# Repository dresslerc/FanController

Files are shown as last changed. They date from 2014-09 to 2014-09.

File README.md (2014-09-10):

FanController - Ceiling Fan Controller 
=========================================

Summary:
This project contains everything you need in order to control your Ceiling Fans from your smart phone.  We do this by tapping into the orginal RF remote of your fan by using Optocouplers. 

There are 3 key components to this project (1 Custom PCB Board, 2 Spark Core Code, and 3 Android/Android Wear app)

The PCB Board can be manufactured at OSHPark (https://oshpark.com/) for about 15$ with a 1-2 week turn around.  In the 'Docs' folder you will find a BOM that contains everything you need to build the board.

The controller for the circuit board is a Spark Core (http://spark.io).  The code is in 'Spark' folder.

You can find the oringal post for this project on https://community.spark.io/t/ceiling-fan-controller/6170

A video of the Android App: https://www.youtube.com/watch?v=2CFPBg5slgM

Android Weaer App: https://www.youtube.com/watch?v=zdxXlhGC8Go

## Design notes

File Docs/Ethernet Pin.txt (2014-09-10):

Color T-568A	Color T-568B	Pin	Description
Brown			Brown			8	GND
Brown/White		Brown/White		7	Fan High
Orange			Green			6	Fan Mid
Blue/White		Blue/White		5	Fan Low
Blue			Blue			4	Fan Off
Orange/White		Green/White		3	DIP 3
Green			Orange			2	DIP 2
Green/White		Orange/White		1	DIP 1

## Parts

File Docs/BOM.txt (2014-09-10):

BOM

Item			Quantity	Unit Price	Total Price		Link	
Female Headers		1		$1.50		$1.50			https://www.sparkfun.com/products/115	
Optoisolator		7		$0.95		$6.65			https://www.sparkfun.com/products/314	
LED 3mm			7		$0.35		$2.45			https://www.sparkfun.com/products/9650	
RJ45 8-Pin		1		$1.50		$1.50			https://www.sparkfun.com/products/643	
Custom PCB		1		$7.73		$7.73		
Spark Core		1		$39.00		$39.00			https://www.spark.io/#

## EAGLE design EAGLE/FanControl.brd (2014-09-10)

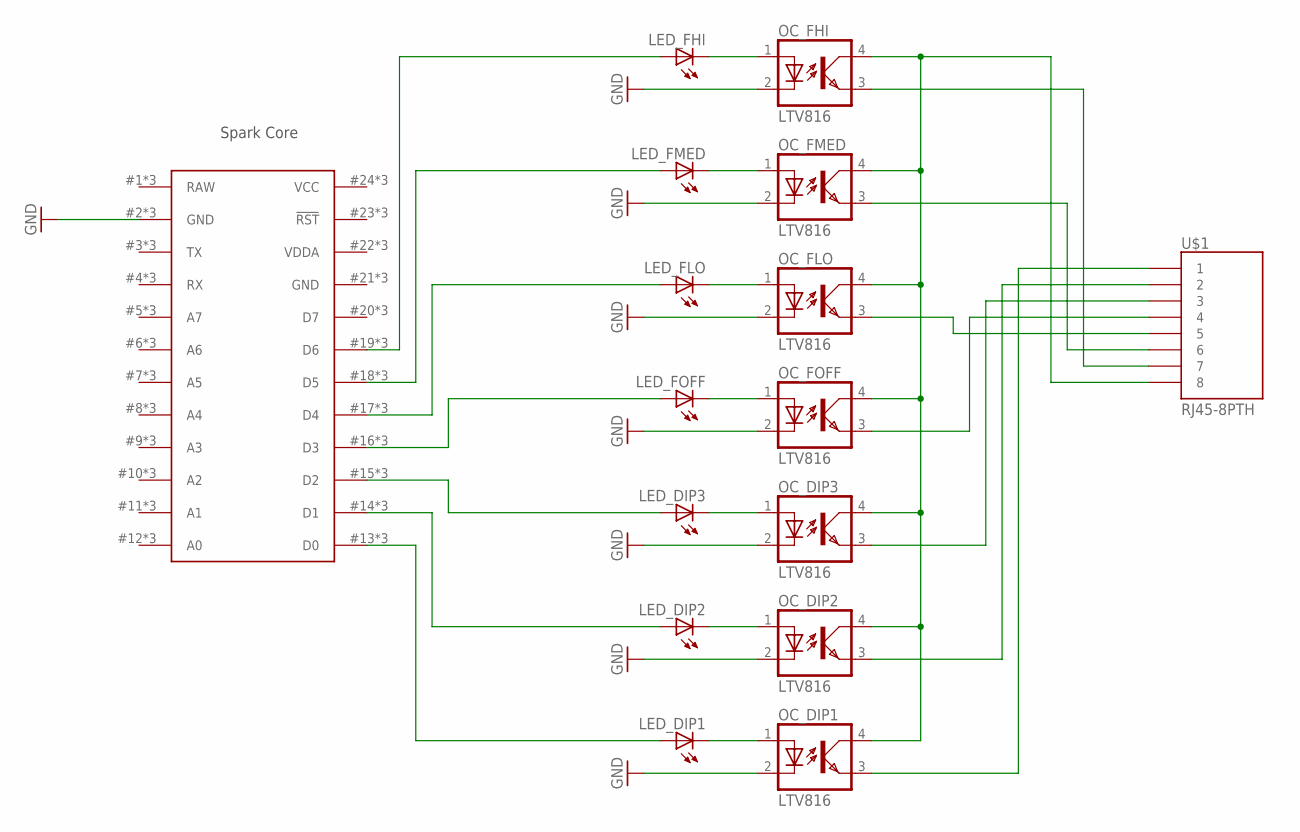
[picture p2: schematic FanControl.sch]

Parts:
LED_DIP1, LED_DIP2, LED_DIP3: LED3MM
LED_FHI: LED3MM
LED_FLO: LED3MM
LED_FMED: LED3MM
LED_FOFF: LED3MM
OC_DIP1, OC_DIP2, OC_DIP3: LTV816; DIL04
OC_FHI: LTV816; DIL04
OC_FLO: LTV816; DIL04
OC_FMED: LTV816; DIL04
OC_FOFF: LTV816; DIL04
U$1: RJ45-8PTH; RJ45-8
U$2: SPARK_CORE; SPARK_CORE_STACKABLE

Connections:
GND: OC_DIP1.2 (C), OC_DIP2.2 (C), OC_DIP3.2 (C), OC_FHI.2 (C), OC_FLO.2 (C), OC_FMED.2 (C), OC_FOFF.2 (C), U$2.2 (GND), U$2.21 (GND), U$2.#2 (GND), U$2.#21 (GND), U$2.@2 (GND), U$2.@21 (GND)
unnamed: OC_DIP1.4 (COL), OC_DIP2.4 (COL), OC_DIP3.4 (COL), OC_FHI.4 (COL), OC_FLO.4 (COL), OC_FMED.4 (COL), OC_FOFF.4 (COL), U$1.8
unnamed: OC_DIP1.3 (EMIT), U$1.1
unnamed: OC_DIP2.3 (EMIT), U$1.2
unnamed: OC_DIP3.3 (EMIT), U$1.3
unnamed: OC_FOFF.3 (EMIT), U$1.4
unnamed: OC_FLO.3 (EMIT), U$1.5
unnamed: OC_FMED.3 (EMIT), U$1.6
unnamed: OC_FHI.3 (EMIT), U$1.7
unnamed: LED_FHI.K (C), OC_FHI.1 (A)
unnamed: LED_FMED.K (C), OC_FMED.1 (A)
unnamed: LED_FLO.K (C), OC_FLO.1 (A)
unnamed: LED_FOFF.K (C), OC_FOFF.1 (A)
unnamed: LED_DIP3.K (C), OC_DIP3.1 (A)
unnamed: LED_DIP2.K (C), OC_DIP2.1 (A)
unnamed: LED_DIP1.K (C), OC_DIP1.1 (A)
unnamed: LED_DIP1.A, U$2.13 (D0), U$2.#13 (D0), U$2.@13 (D0)
unnamed: LED_DIP2.A, U$2.14 (D1), U$2.#14 (D1), U$2.@14 (D1)
unnamed: LED_DIP3.A, U$2.15 (D2), U$2.#15 (D2), U$2.@15 (D2)
unnamed: LED_FOFF.A, U$2.16 (D3), U$2.#16 (D3), U$2.@16 (D3)
unnamed: LED_FLO.A, U$2.17 (D4), U$2.#17 (D4), U$2.@17 (D4)
unnamed: LED_FMED.A, U$2.18 (D5), U$2.#18 (D5), U$2.@18 (D5)
unnamed: LED_FHI.A, U$2.19 (D6), U$2.#19 (D6), U$2.@19 (D6)
RAW: U$2.1 (RAW), U$2.#1 (RAW), U$2.@1 (RAW)
VCC: U$2.24 (VCC), U$2.#24 (VCC), U$2.@24 (VCC)
VDDA: U$2.22 (VDDA), U$2.#22 (VDDA), U$2.@22 (VDDA)

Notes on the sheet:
Spark Core

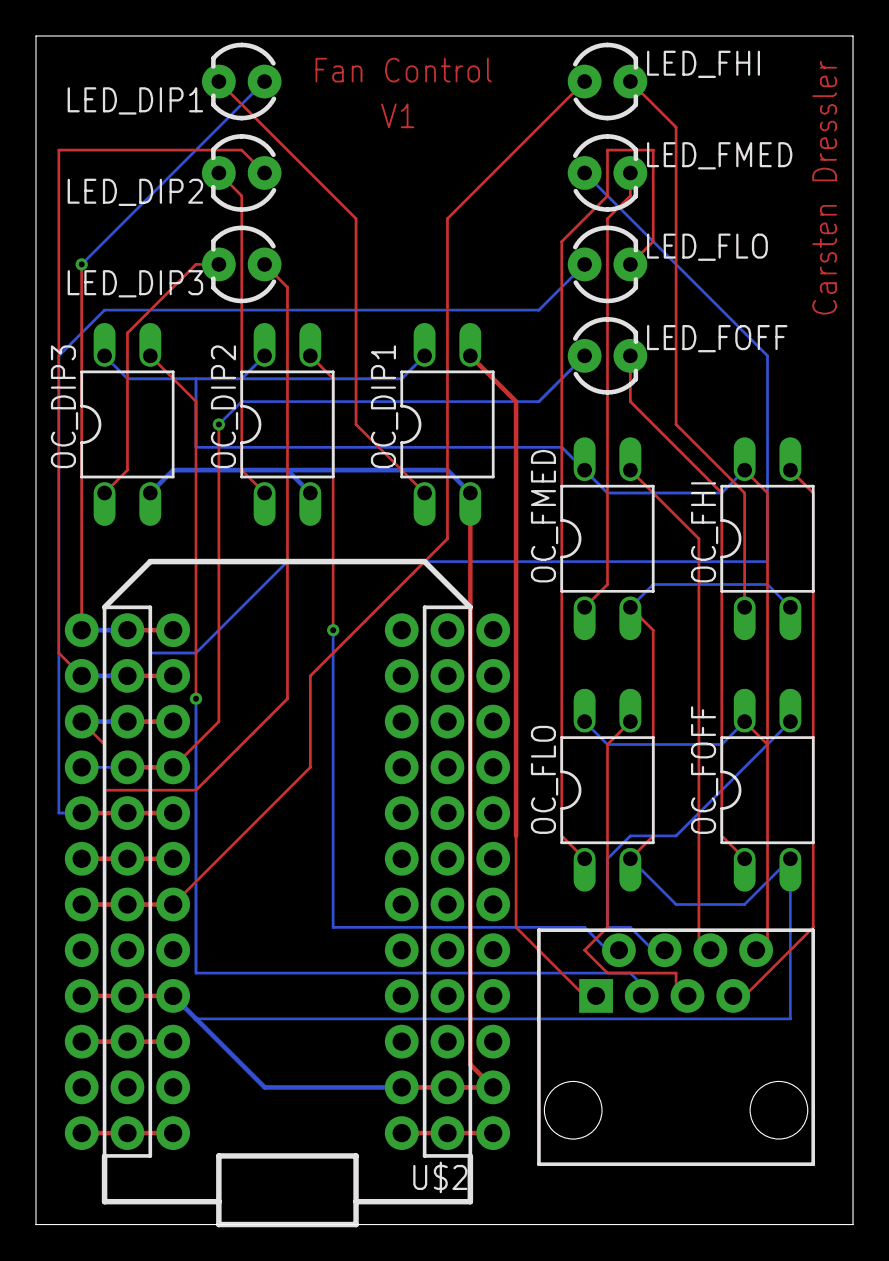
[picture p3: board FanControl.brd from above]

Board: 2 copper layers, 45.4 x 66.0 mm, 16 parts (0 on the bottom side), 26 nets.

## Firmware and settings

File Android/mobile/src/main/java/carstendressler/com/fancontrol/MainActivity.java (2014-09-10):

package carstendressler.com.fancontrol;

import android.app.Activity;
import android.app.AlertDialog;
import android.app.ListActivity;
import android.content.Context;
import android.content.DialogInterface;
import android.content.Intent;
import android.os.Bundle;
import android.util.Log;
import android.view.Menu;
import android.view.MenuItem;
import android.view.View;
import android.view.Window;
import android.widget.ListView;
import android.widget.Toast;

import com.google.gson.Gson;
import com.google.gson.internal.LinkedTreeMap;

import java.io.IOException;
import java.util.ArrayList;
import java.util.HashMap;
import java.util.List;
import java.util.Map;

import carstendressler.com.util.HTTPHeader;
import carstendressler.com.util.SimpleHttpClient;
import carstendressler.com.util.SparkResponse;
import io.spark.core.cloud.AuthenicationResponse;

/**
 * Created by Carsten on 7/25/2014.
 */
public class MainActivity extends ListActivity {

    private FanAdapter _adapter;
    private List<FanEntity> _fans = null; //new ArrayList<FanEntity>();
    private Context _context;
    private Activity _activity;

    //public String _accessToken = "9f144d072f915ab729d60e724282d36ce44bc310";
    //public String _deviceId = "48ff70065067555030231387";

    @Override
    protected void onCreate(Bundle savedInstanceState) {
        super.onCreate(savedInstanceState);
        // setContentView(R.layout.activity_main);
        Log.v("FANCTRL", "appcreated");
        this.requestWindowFeature(Window.FEATURE_INDETERMINATE_PROGRESS);

        _context = this;
        _activity = this;

        _fans =  SettingsActivity.SettingsFragment.getConfiguredFans(_context);

        _adapter = new FanAdapter(this, R.layout.listitem, _fans);
        this.setListAdapter(_adapter);

        _adapter.notifyDataSetChanged();

        getStatus();

    }

    @Override
    protected void onResume() {
        super.onResume();

        _fans.clear();
        _fans.addAll(SettingsActivity.SettingsFragment.getConfiguredFans(_context));

        _adapter.notifyDataSetChanged();

        getStatus();
    }

    @Override
    protected void onListItemClick(ListView l, View v, final int position,
                                   long id) {
        // TODO Auto-generated method stub
        super.onListItemClick(l, v, position, id);

        AlertDialog.Builder builder = new AlertDialog.Builder(_context);
        builder.setTitle("Set Fan Mode");
        builder.setItems(R.array.mode_array,
                new DialogInterface.OnClickListener() {
                    public void onClick(DialogInterface dialog, int which) {
                        // _fans.get(position).Name
                        String mode = null;

                        if (which == 0)
                            mode = "hi";

                        if (which == 1)
                            mode = "me";

                        if (which == 2)
                            mode = "lo";

                        if (which == 3)
                            mode = "of";

                        SendCommand(
                                String.valueOf(_fans.get(position).Address),
                                mode);

                        // Toast.makeText(_context,
                        // String.valueOf(_fans.get(position).Address),
                        // Toast.LENGTH_LONG).show();

                    }
                });
        builder.show();

    }

    @Override
    public boolean onCreateOptionsMenu(Menu menu) {
        // Inflate the menu; this adds items to the action bar if it is present.
        getMenuInflater().inflate(R.menu.main, menu);
        return true;
    }


    @Override
    public boolean onMenuItemSelected(int featureId, MenuItem item) {

        switch (item.getItemId()) {
            case R.id.action_settings:

                Intent SettingsIntent = new Intent(_context, SettingsActivity.class);
                this.startActivity(SettingsIntent);
                break;

            case R.id.action_refresh:

                getStatus();

                break;

        }

        return super.onMenuItemSelected(featureId, item);
    }



    private void SendCommand(final String Address, final String Mode) {

        final String deviceID = SettingsActivity.SettingsFragment.getDeviceID(_context);

        Toast.makeText(_context, Address + Mode, Toast.LENGTH_LONG).show();

        new Thread(new Runnable() {
            public void run() {

                Gson gson = new Gson();
                String buffer = null;

                try {
                    buffer = SimpleHttpClient.httpPost("https://api.spark.io/v1/devices/" + deviceID + "/fancontrol","access_token=" + SettingsActivity.SettingsFragment.getAccessToken(_context) + "&args=" + Address + Mode);

                    SparkResponse resp = gson.fromJson(buffer, SparkResponse.class);

                    int ArrayAddress = 0;
                    for (int i = 0; i < _fans.size(); i++) {
                        if (_fans.get(i).Address == Integer.valueOf(Address))
                            ArrayAddress = i;
                    }

                    if (resp.return_value == -1)
                        _fans.get(ArrayAddress).Status = FanEntity.Status1.UNKNOWN;

                    if (resp.return_value == 0)
                        _fans.get(ArrayAddress).Status = FanEntity.Status1.OFF;

                    if (resp.return_value == 1)
                        _fans.get(ArrayAddress).Status = FanEntity.Status1.LOW;

                    if (resp.return_value == 2)
                        _fans.get(ArrayAddress).Status = FanEntity.Status1.MEDIUM;

                    if (resp.return_value == 3)
                        _fans.get(ArrayAddress).Status = FanEntity.Status1.HIGH;

                    // Runs next code in UI Thread
                    _activity.runOnUiThread(new Runnable() {
                        public void run() {
                            _adapter.notifyDataSetChanged();

                        }
                    });

                } catch (IOException e) {
                    // TODO Auto-generated catch block
                    e.printStackTrace();
                }

            }
        }).start();

    }

    private void getStatus() {

        final String deviceID = SettingsActivity.SettingsFragment.getDeviceID(_context);

        if (deviceID.length() == 0)
            return;

        setProgressBarIndeterminateVisibility(Boolean.TRUE);

        new Thread(new Runnable() {
            public void run() {

                Gson gson = new Gson();
                String buffer = null;

                for (int i = 0; i < _fans.size(); i++) {

                    buffer = null;

                    try {
                        String accessToken = SettingsActivity.SettingsFragment.getAccessToken(_context);

                        if (accessToken.length() == 0) {
                            // Runs next code in UI Thread
                            _activity.runOnUiThread(new Runnable() {
                                public void run() {
                                    setProgressBarIndeterminateVisibility(Boolean.FALSE);
                                }
                            });

                            return;

                        }


                        buffer = SimpleHttpClient.httpPost("https://api.spark.io/v1/devices/" + deviceID + "/fanstatus" ,"access_token=" + accessToken + "&args=" + String.valueOf(_fans.get(i).Address));
                        SparkResponse resp = gson.fromJson(buffer, SparkResponse.class);

                        if (resp.return_value == -1)
                            _fans.get(i).Status = FanEntity.Status1.UNKNOWN;

                        if (resp.return_value == 0)
                            _fans.get(i).Status = FanEntity.Status1.OFF;

                        if (resp.return_value == 1)
                            _fans.get(i).Status = FanEntity.Status1.LOW;

                        if (resp.return_value == 2)
                            _fans.get(i).Status = FanEntity.Status1.MEDIUM;

                        if (resp.return_value == 3)
                            _fans.get(i).Status = FanEntity.Status1.HIGH;

                        // Runs next code in UI Thread
                        _activity.runOnUiThread(new Runnable() {
                            public void run() {
                                _adapter.notifyDataSetChanged();
                                setProgressBarIndeterminateVisibility(Boolean.FALSE);
                            }
                        });

                    } catch (final IOException e) {
                        // TODO Auto-generated catch block
                        e.printStackTrace();

                        final String errorMsg = buffer;

                        // Runs next code in UI Thread
                        _activity.runOnUiThread(new Runnable() {
                            public void run() {
                                _adapter.notifyDataSetChanged();
                                setProgressBarIndeterminateVisibility(Boolean.FALSE);
                                Toast.makeText(_context, e.getMessage(), Toast.LENGTH_LONG).show();

                            }
                        });


                    }
                }
            }
        }).start();
    }

    private void getAccessToken(final String Email, final String Password) {

        setProgressBarIndeterminateVisibility(Boolean.TRUE);

        new Thread(new Runnable() {
            public void run() {

                Map<String, String> jsonMap = new HashMap<String, String>();

                jsonMap.put("username",Email);
                jsonMap.put("password", Password);

                String json = new Gson().toJson(jsonMap);

                List<HTTPHeader> headers = new ArrayList<HTTPHeader>();
                headers.add(new HTTPHeader("Content-Type","application/json"));

                String respBuffer = null;
                try {
                    respBuffer = SimpleHttpClient.httpPost("https://www.spark.io/sign-in", json, headers);
                } catch (IOException e) {
                }
                AuthenicationResponse authResp = new Gson().fromJson(respBuffer, AuthenicationResponse.class);

                headers.add(new HTTPHeader("Authorization","Bearer " + authResp.auth_token.token));
                try {
                    respBuffer = SimpleHttpClient.httpGet("https://www.spark.io/access-token", headers);
                } catch (IOException e) {
                }
                LinkedTreeMap accessTokenResp = new Gson().fromJson(respBuffer, LinkedTreeMap.class);


            }
        }).start();

    }

}

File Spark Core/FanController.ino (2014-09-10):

const int io_dip1 = 0;
const int io_dip2 = 1;
const int io_dip3 = 2;
const int io_fanoff = 3;
const int io_fanlo = 4;
const int io_fanmed = 5;
const int io_fanhigh = 6;

int fanStat[7];

void setup() {
    
    for (int i = 0; i < 7; i++)  {
        fanStat[i] = -1;
    }
        
    // Controls onboard RGB led
    RGB.control(true);
    RGB.color(0, 0, 30);
    
    // Sets up Pins Modes
    pinMode(io_dip1, OUTPUT);
    pinMode(io_dip2, OUTPUT);
    pinMode(io_dip3, OUTPUT);
    pinMode(io_fanoff, OUTPUT);
    pinMode(io_fanlo, OUTPUT);
    pinMode(io_fanmed, OUTPUT);
    pinMode(io_fanhigh, OUTPUT);
  
    // Sets Cloud function calls
    Spark.function("fancontrol", fanControl);
    Spark.function("fanstatus", fanStatus);
    
    //Serial.begin(9600);
    
}

void loop() {

}

int fanStatus(String command)
{
    int address = command.toInt();;
    
    // Memory
    return fanStat[address];
    
    // EEPROM
    //return SparkFlash_read(address);
}

int fanControl(String command) 
{
   RGB.color(0, 30, 0);
   int address = setDipSwitches(command.substring(0,1));
   delay(200);
   
   // Memory
   fanStat[address] = setFanMode(command.substring(1));
   
   // EEPROM
   //SparkFlash_write(address * 2,  setFanMode(command.substring(1)));
   
   delay(1000);
   gpioReset();
   RGB.color(0, 0, 30);
   
   // Memory
   return fanStat[address];
   
   // EEPROM
   //return SparkFlash_read(address);
}

int setDipSwitches(String address) {
    
    if (address == "0") {
        digitalWrite(io_dip1, LOW);
        digitalWrite(io_dip2, LOW);
        digitalWrite(io_dip3, LOW);
        
        return 0;
    }
    
    if (address == "1") {
        digitalWrite(io_dip1, LOW);
        digitalWrite(io_dip2, LOW);
        digitalWrite(io_dip3, HIGH);
        
        return 1;
    }

    if (address == "2") {
        digitalWrite(io_dip1, LOW);
        digitalWrite(io_dip2, HIGH);
        digitalWrite(io_dip3, LOW);
        
        return 2;
    }
    
    if (address == "3") {
        digitalWrite(io_dip1, LOW);
        digitalWrite(io_dip2, HIGH);
        digitalWrite(io_dip3, HIGH);
        
        return 3;
    }
    
    if (address == "4") {
        digitalWrite(io_dip1, HIGH);
        digitalWrite(io_dip2, LOW);
        digitalWrite(io_dip3, LOW);
        
        return 4;
    }            
   
    if (address == "5") {
        digitalWrite(io_dip1, HIGH);
        digitalWrite(io_dip2, LOW);
        digitalWrite(io_dip3, HIGH);
        
        return 5;
    }     

    if (address == "6") {
        digitalWrite(io_dip1, HIGH);
        digitalWrite(io_dip2, HIGH);
        digitalWrite(io_dip3, LOW);
        
        return 6;
    }      
   
    if (address == "7") {
        digitalWrite(io_dip1, HIGH);
        digitalWrite(io_dip2, HIGH);
        digitalWrite(io_dip3, HIGH);
        
        return 7;
    } 
    
    return -1;
}

int setFanMode(String command) {
    
    //Serial.println(command);
    
    if (command == "of") {
        digitalWrite(io_fanoff, HIGH);
        
        return 0;
    }
    
    if (command == "lo") {
        digitalWrite(io_fanlo, HIGH);
        
        return 1;
    }
    
    if (command == "me") {
        digitalWrite(io_fanmed, HIGH);
        
        return 2;
    }
    
    if (command == "hi") {
        digitalWrite(io_fanhigh, HIGH);
        
        return 3;
    }
    
    return -1;
}

void gpioReset() {
    
    digitalWrite(io_dip1, LOW);
    digitalWrite(io_dip2, LOW);
    digitalWrite(io_dip3, LOW);
    digitalWrite(io_fanoff, LOW);
    digitalWrite(io_fanlo, LOW);
    digitalWrite(io_fanmed, LOW);
    digitalWrite(io_fanhigh, LOW);
    
}

int SparkFlash_read(int address)
{
  if (address & 1)
    return -1; // error, can only access half words

  uint8_t values[2];
  sFLASH_ReadBuffer(values, 0x80000 + address, 2);
  return (values[0] << 8) | values[1];
}

int SparkFlash_write(int address, uint16_t value)
{
  if (address & 1)
    return -1; // error, can only access half words

  uint8_t values[2] = {
    (uint8_t)((value >> 8) & 0xff),
    (uint8_t)(value & 0xff)
  };
  sFLASH_WriteBuffer(values, 0x80000 + address, 2);
  return 2; // or anything else signifying it worked
}

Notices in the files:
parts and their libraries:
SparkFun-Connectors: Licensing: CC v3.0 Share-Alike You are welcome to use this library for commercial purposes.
